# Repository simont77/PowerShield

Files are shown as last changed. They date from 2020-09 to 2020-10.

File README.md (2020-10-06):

# PowerShield
 This design is an extension board for any Raspberry Pi based astronomy tool, like Astroberry or StellarMate.
 The repository contains the electrical (ECAD) and mechanical (MCAD) design files.
 
# Electrical Design (ECAD)
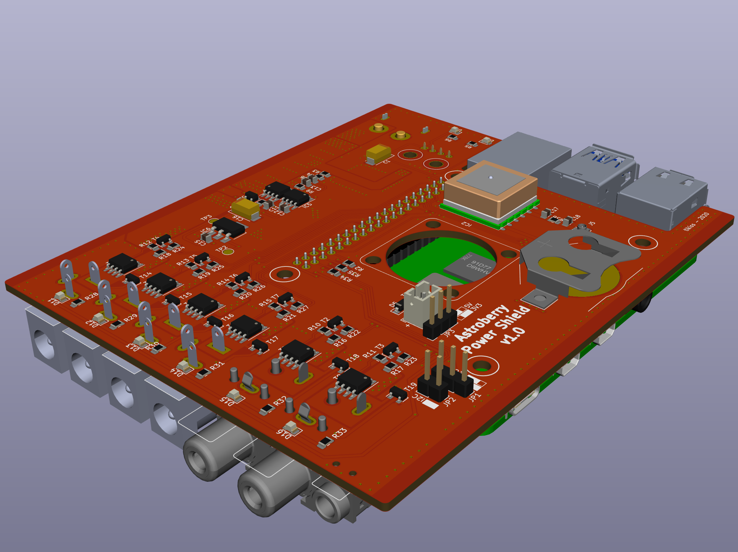
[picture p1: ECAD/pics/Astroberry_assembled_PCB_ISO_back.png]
 
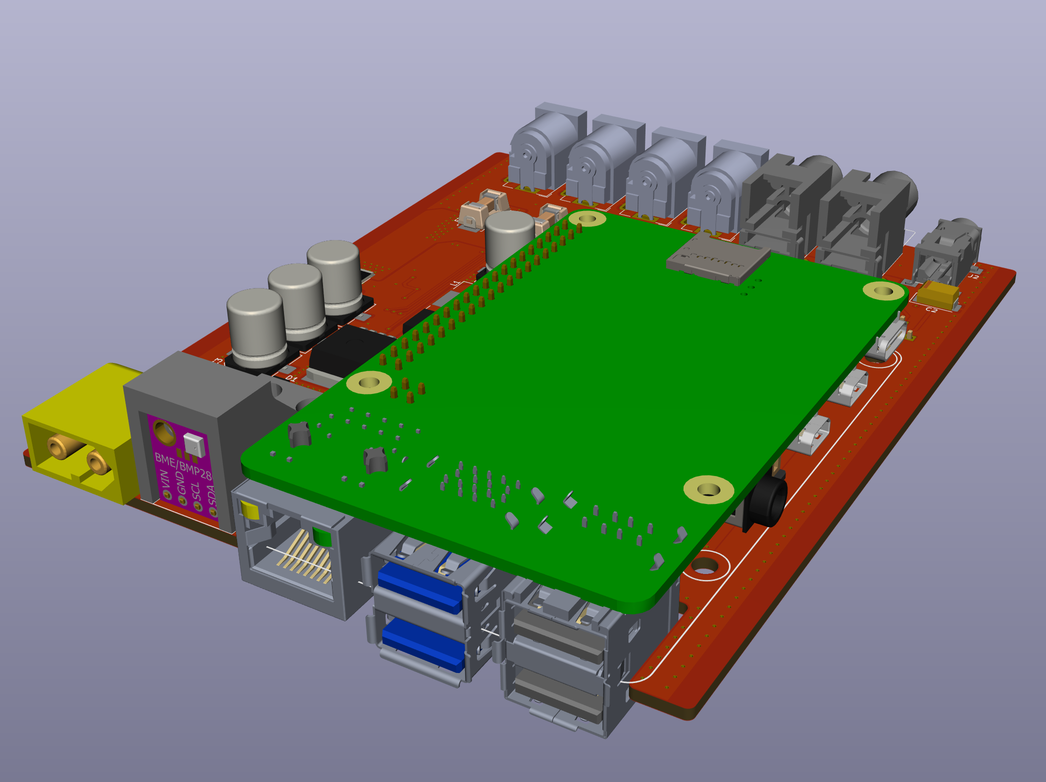
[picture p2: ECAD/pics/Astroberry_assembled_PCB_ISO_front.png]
 
 
## Features
* One power input
* 4pcs switchable (ON/OFF) not regulated outpus, each has maximum 3A load capability (CH1 ... CH4 - DC jack)
* 2pcs switchable (ON/OFF) or PWM controlled outputs, also with maximum 3A load capability for dew heaters (DEW1 and DEW2 - RCA)
* Fuse monitoring signals for each outputs, to detect fuse burn
* Integrated 5V/3A SMPS to power Raspberry Pi
* Integrated BME280 to measure, temperature, pressure and humidity
* Integrated GPS module with integrated antenna
* Connecting external GPS antenna
* Fan connector, supports 3,3V and 5V fans, fan can be switched ON/OFF.
* Input voltage monitoring, maximal range 20V
* Total output current monitoring, maximal range 16A, allowed total ouput curren is 15A
* Reverse polarity protection
* 4 pin 3,5mm jack to connect external sensors, or extension boards, communication interface can be selected with jumpers, I2C or one wire
* LED feedback for each outputs
* LED for GPS, e.g. show 3D fix (usage of this LED is SW dependent)

List of used ports and their funtions will be available in the Wiki section.

## What works
 Every features listed above are tested and working. Testing was done with terminal commands, like "gpio" or with testing scripts.

## What is not working
 Check the "Issues" section.

## What is needed
* INDI driver is on the way: https://github.com/rkaczorek/astroberry-powershield
* I am planning to perform thermal measurement, to see what is board thermal behaviour under maximal load condition.

# Mechanical Design (MCAD)
 Mechanical design was done based on Hammond Extruded Aluminum Enclosures design.
 
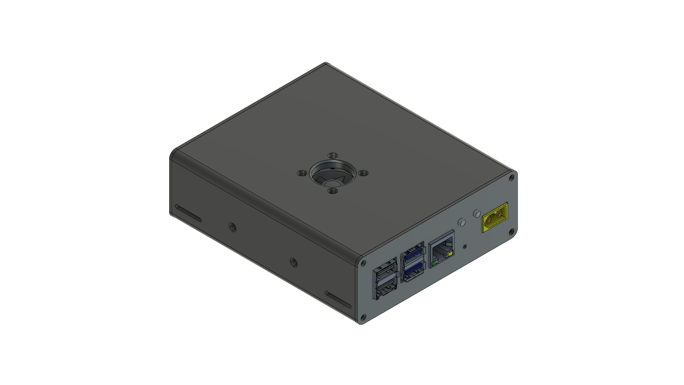
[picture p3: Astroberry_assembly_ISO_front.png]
 
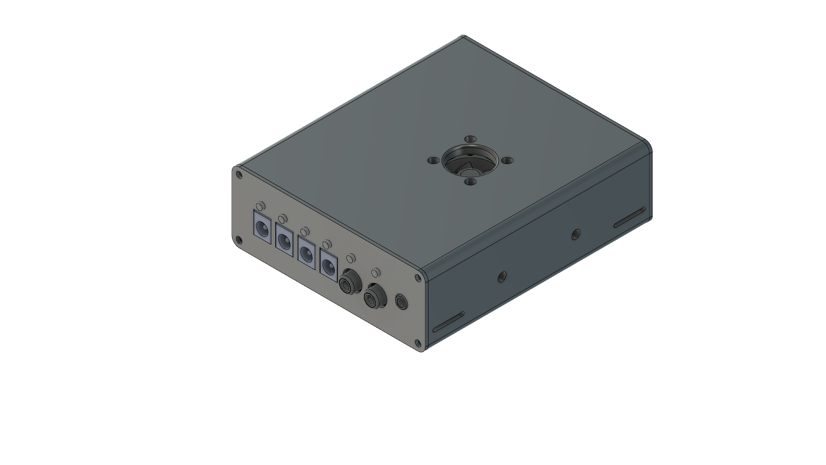
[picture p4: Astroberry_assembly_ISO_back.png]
 
 
 The "extruded" part of the housing is prepared for 3D printing.
 The front and back plates are design in KiCAD as well and manufactured from 1,6mm thick PCB, the panelized gerber files are uploaded in the repository.

# Licence
 The licence is the CERN Open Hardware Licence version 2, and variant CERN-OHL-S
 Check the "LICENCE" file or original location of the licence:
 https://ohwr.org/cern_ohl_s_v2.txt
 
# Donation
If you like the design, think about to support me with a cup of coffee, a glas of beer...
This could help to develop further this design.



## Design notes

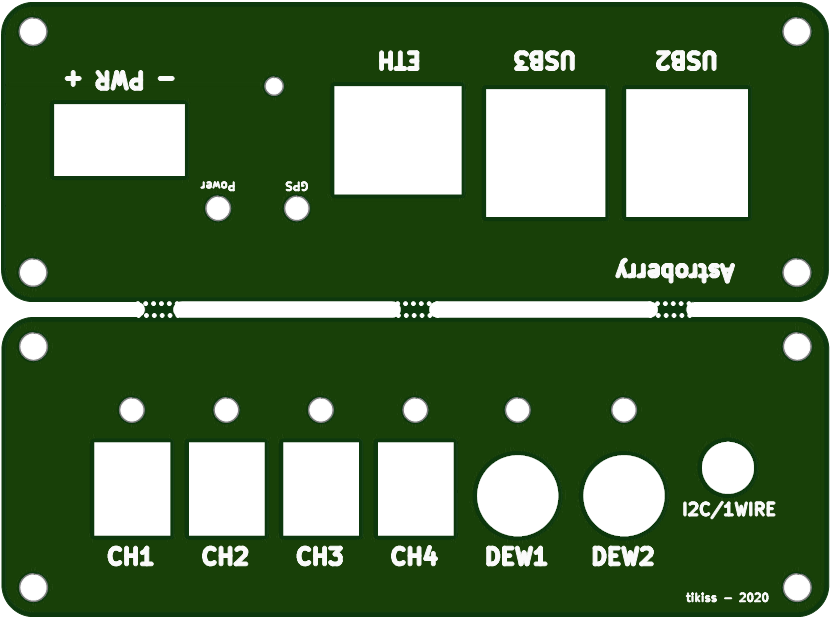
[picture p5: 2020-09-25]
MCAD/Front_Back_Plates/pics/Astroberry_Front_back_Top.png

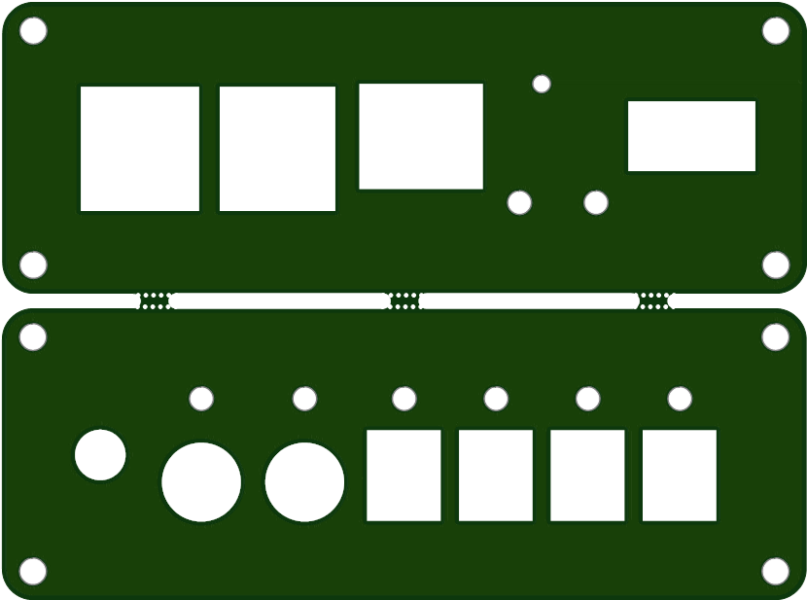
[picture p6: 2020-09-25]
MCAD/Front_Back_Plates/pics/Astroberry_Front_back_Bottom.png

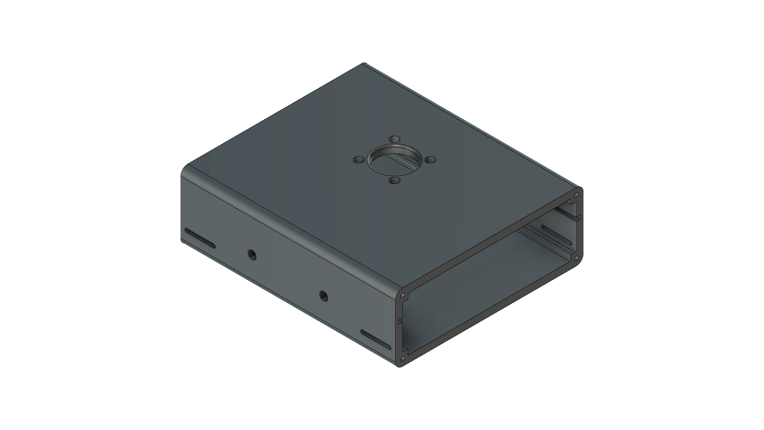
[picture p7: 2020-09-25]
MCAD/Housing/Astroberry_housing_3D.png

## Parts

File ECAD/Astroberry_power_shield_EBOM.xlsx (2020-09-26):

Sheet: EBOM_groupped
Designer | Tibor Kiss
Source: | Astroberry Power Shield v1.0
Date: | 2020 September 26, Saturday 18:41:44
Tool: | Eeschema (5.1.6-0-10_14)
Generator: | bom_csv_grouped_by_value.py
Component Count: | 125
Item | Qty | Reference(s) | Value | LibPart | Footprint | Reichelt
1 | 1 | BT1 | CR2032 | Device:Battery_Cell | Battery:BatteryHolder_Keystone_3002_1x2032 | -
2 | 5 | C1, C2, C7, C8, C16 | 10u | Device:CP | Capacitor_Tantalum_SMD:CP_EIA-6032-28_Kemet-C_Pad2.25x2.35mm_HandSolder | T491C 10U 25
3 | 4 | C3, C4, C5, C14 | 330u | Device:CP | Capacitor_SMD:C_Elec_8x10.2 | VF 330/25 K-F
4 | 7 | C6, C9, C10, C11, C12, C15, C20 | 100n | Device:C | Capacitor_SMD:C_0805_2012Metric | KEM X7R0805 100N
5 | 1 | C13 | 10n | Device:C | Capacitor_SMD:C_0805_2012Metric | KEM X7R0805 10N
6 | 2 | C17, C18 | n.a. | Device:C | Capacitor_SMD:C_0805_2012Metric | -
7 | 1 | C19 | 4,7u | Device:C | Capacitor_SMD:C_0805_2012Metric
8 | 1 | D1 | BZX84C18 | Diode:BZX84Cxx | Diode_SMD:D_SOT-23_ANK | BZX 84-C18 NXP
9 | 1 | D2 | Blue | Device:LED | LED_SMD:LED_0805_2012Metric
10 | 1 | D3 | Green | Device:LED | LED_SMD:LED_0805_2012Metric | SMD-LED 0805 GN
11 | 1 | D4 | SK54C | Diode:B320 | Diode_SMD:D_SMC | SK 54C
12 | 2 | D5, D6 | BAT42W-V | Diode:BAT42W-V | Diode_SMD:D_SOD-123 | BAT 42W
13 | 6 | D11, D12, D13, D14, D15, D16 | Red | Device:LED | LED_SMD:LED_0805_2012Metric | SMD-LED 0805 RT
14 | 2 | D17, D18 | SK 34SMA | Device:D_Schottky | Diode_SMD:D_SMA | SK 34SMA DIO
15 | 6 | F1, F2, F3, F4, F5, F6 | 4A | Device:Fuse | MyFuses:Litt_154_OMNI_BLOK | SMD-HASF 4,0A
16 | 4 | H3, H4, H5, H6 | Fan | Mechanical:MountingHole | MountingHole:MountingHole_3.2mm_M3 | -
17 | 1 | IC1 | INA138 | Amplifier_Current:INA138 | Package_TO_SOT_SMD:SOT-23-5 | INA 138 NA/250
18 | 1 | IC2 | L80-M39 | MyGPS:L80-M39 | MyGPS:L80-M39
19 | 1 | IC3 | LM2596S-5 | Regulator_Switching:LM2596S-5 | Package_TO_SOT_SMD:TO-263-5_TabPin3 | LM 2596 S-5.0
20 | 1 | IC4 | OPA340UA | Amplifier_Operational:OPA340UA | Package_SO:SOIC-8_3.9x4.9mm_P1.27mm | OPA 340 UA
21 | 1 | IC5 | MCP3202 | Analog_ADC:MCP3202 | Package_SO:SOIC-8_3.9x4.9mm_P1.27mm | MCP3202-CI/SN
22 | 1 | IC6 | LM1117-3.3 | Regulator_Linear:LM1117-3.3 | Package_TO_SOT_SMD:SOT-223 | TS 1117 BCW33
23 | 1 | J1 | BME280 | Connector:Conn_01x04_Female | MyMechanic:BME280_holder
24 | 1 | J2 | I2C/1WIRE | MyConnectors:AudioJack_4pin | MyConnectors:LUM_1503_13 | LUM 1503-13V
25 | 1 | J3 | Power | Connector:Conn_01x02_Male | MyConnectors:XT60PW-M20 | -
26 | 1 | J4 | Raspberry Pi | Connector_Generic:Conn_02x20_Odd_Even | MyRaspberry:Raspberry_pi_4_w_mounting_holes | MPE 094-2-040
27 | 1 | J5 | Ext_Ant | Connector:Conn_Coaxial | Connector_Coaxial:U.FL_Molex_MCRF_73412-0110_Vertical
28 | 4 | J6, J7, J8, J9 | DC_Jack_2.1mm | MyConnectors:DC_Jack_2.1mm | MyConnectors:BKL_DC_Jack_2.1mm | DC BU21 90
29 | 1 | J10 | Dew_CH1 | Connector:Conn_Coaxial | MyConnectors:LUM_1553 | LUM 1553 02 SW
30 | 1 | J11 | Dew_CH2 | Connector:Conn_Coaxial | MyConnectors:LUM_1553 | LUM 1553 02 WS
31 | 1 | J12 | FAN | Connector:Conn_01x02_Male | Connector_JST:JST_PH_B2B-PH-K_1x02_P2.00mm_Vertical
32 | 1 | JP1 | 1WIRE/I2C | Jumper:Jumper_3_Bridged12 | Connector_PinHeader_2.54mm:PinHeader_1x03_P2.54mm_Vertical
33 | 1 | JP2 | I2C_CLK | Jumper:Jumper_2_Open | Connector_PinHeader_2.54mm:PinHeader_1x02_P2.54mm_Vertical
34 | 1 | JP3 | 5V/3V3 | Jumper:Jumper_3_Bridged12 | Connector_PinHeader_2.54mm:PinHeader_1x03_P2.54mm_Vertical
35 | 1 | L1 | 33u | Device:L | Inductor_SMD:L_12x12mm_H8mm | L-PIS4728 33¬µ
36 | 8 | R1, R3, R16, R17, R18, R19, R20, R21 | 10k | Device:R | Resistor_SMD:R_0805_2012Metric | RND 0805 1 10K
37 | 9 | R2, R10, R11, R12, R13, R14, R15, R34, R35 | 4k7 | Device:R | Resistor_SMD:R_0805_2012Metric | RND 0805 1 4,7K
38 | 7 | R4, R22, R23, R24, R25, R26, R27 | 1k8 | Device:R | Resistor_SMD:R_0805_2012Metric | RND 0805 1 1,8K
39 | 7 | R5, R28, R29, R30, R31, R32, R33 | 150 | Device:R | Resistor_SMD:R_0805_2012Metric | RND 0805 1 150
40 | 1 | R6 | 270 | Device:R | Resistor_SMD:R_0805_2012Metric | RND 0805 1 270
41 | 1 | R7 | 10m | Device:R | Resistor_SMD:R_2512_6332Metric | ISA SMT-R010-1
42 | 1 | R8 | 100k | Device:R | Resistor_SMD:R_0805_2012Metric | RND 0805 1 100K
43 | 1 | R9 | 15k | Device:R | Resistor_SMD:R_0805_2012Metric | RND 0805 1 15K
44 | 1 | R36 | 0 | Device:R | Resistor_SMD:R_0805_2012Metric
45 | 1 | R37 | 1k | Device:R | Resistor_SMD:R_0805_2012Metric | RND 0805 1 1K
46 | 1 | T1 | AOD403 | Transistor_FET:SUD19P06-60 | Package_TO_SOT_SMD:TO-252-2 | AO D403
47 | 13 | T2, T3, T4, T5, T6, T7, T14, T15, T16, T17, T18, T19, T21 | DTC114E | Transistor_BJT:DTC114E | Package_TO_SOT_SMD:SOT-23 | PDTC 114ET NXP
48 | 6 | T8, T9, T10, T11, T12, T13 | AO4407A | Transistor_FET:IRF7404 | Package_SO:SOIC-8_3.9x4.9mm_P1.27mm | AO 4407A
49 | 1 | T20 | FDN 357N | Transistor_FET:ZXMN3A01F | Package_TO_SOT_SMD:SOT-23 | FDN 357N

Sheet: EBOM
Designer | Tibor Kiss
Source: | Astroberry Power Shield v1.0
Date: | 2020 September 26, Saturday 18:41:44
Tool: | Eeschema (5.1.6-0-10_14)
Generator: | bom_csv_grouped_by_value.py
Component Count: | 125
Reference(s) | Value | LibPart | Footprint | Reichelt
BT1 | CR2032 | Device:Battery_Cell | Battery:BatteryHolder_Keystone_3002_1x2032 | -
C1 | 10u | Device:CP | Capacitor_Tantalum_SMD:CP_EIA-6032-28_Kemet-C_Pad2.25x2.35mm_HandSolder | T491C 10U 25
C2 | 10u | Device:CP | Capacitor_Tantalum_SMD:CP_EIA-6032-28_Kemet-C_Pad2.25x2.35mm_HandSolder | T491C 10U 25
C3 | 330u | Device:CP | Capacitor_SMD:C_Elec_8x10.2 | VF 330/25 K-F
C4 | 330u | Device:CP | Capacitor_SMD:C_Elec_8x10.2 | VF 330/25 K-F
C5 | 330u | Device:CP | Capacitor_SMD:C_Elec_8x10.2 | VF 330/25 K-F
C6 | 100n | Device:C | Capacitor_SMD:C_0805_2012Metric | KEM X7R0805 100N
C7 | 10u | Device:CP | Capacitor_Tantalum_SMD:CP_EIA-6032-28_Kemet-C_Pad2.25x2.35mm_HandSolder | T491C 10U 25
C8 | 10u | Device:CP | Capacitor_Tantalum_SMD:CP_EIA-6032-28_Kemet-C_Pad2.25x2.35mm_HandSolder | T491C 10U 25
C9 | 100n | Device:C | Capacitor_SMD:C_0805_2012Metric | KEM X7R0805 100N
C10 | 100n | Device:C | Capacitor_SMD:C_0805_2012Metric | KEM X7R0805 100N
C11 | 100n | Device:C | Capacitor_SMD:C_0805_2012Metric | KEM X7R0805 100N
C12 | 100n | Device:C | Capacitor_SMD:C_0805_2012Metric | KEM X7R0805 100N
C13 | 10n | Device:C | Capacitor_SMD:C_0805_2012Metric | KEM X7R0805 10N
C14 | 330u | Device:CP | Capacitor_SMD:C_Elec_8x10.2 | VF 330/25 K-F
C15 | 100n | Device:C | Capacitor_SMD:C_0805_2012Metric | KEM X7R0805 100N
C16 | 10u | Device:CP | Capacitor_Tantalum_SMD:CP_EIA-6032-28_Kemet-C_Pad2.25x2.35mm_HandSolder | T491C 10U 25
C17 | n.a. | Device:C | Capacitor_SMD:C_0805_2012Metric | -
C18 | n.a. | Device:C | Capacitor_SMD:C_0805_2012Metric | -
C19 | 4,7u | Device:C | Capacitor_SMD:C_0805_2012Metric
C20 | 100n | Device:C | Capacitor_SMD:C_0805_2012Metric | KEM X7R0805 100N
D1 | BZX84C18 | Diode:BZX84Cxx | Diode_SMD:D_SOT-23_ANK | BZX 84-C18 NXP
D2 | Blue | Device:LED | LED_SMD:LED_0805_2012Metric
D3 | Green | Device:LED | LED_SMD:LED_0805_2012Metric | SMD-LED 0805 GN
D4 | SK54C | Diode:B320 | Diode_SMD:D_SMC | SK 54C
D5 | BAT42W-V | Diode:BAT42W-V | Diode_SMD:D_SOD-123 | BAT 42W
D6 | BAT42W-V | Diode:BAT42W-V | Diode_SMD:D_SOD-123 | BAT 42W
D11 | Red | Device:LED | LED_SMD:LED_0805_2012Metric | SMD-LED 0805 RT
D12 | Red | Device:LED | LED_SMD:LED_0805_2012Metric | SMD-LED 0805 RT
D13 | Red | Device:LED | LED_SMD:LED_0805_2012Metric | SMD-LED 0805 RT
D14 | Red | Device:LED | LED_SMD:LED_0805_2012Metric | SMD-LED 0805 RT
D15 | Red | Device:LED | LED_SMD:LED_0805_2012Metric | SMD-LED 0805 RT
D16 | Red | Device:LED | LED_SMD:LED_0805_2012Metric | SMD-LED 0805 RT
D17 | SK 34SMA | Device:D_Schottky | Diode_SMD:D_SMA | SK 34SMA DIO
D18 | SK 34SMA | Device:D_Schottky | Diode_SMD:D_SMA | SK 34SMA DIO
F1 | 4A | Device:Fuse | MyFuses:Litt_154_OMNI_BLOK | SMD-HASF 4,0A
F2 | 4A | Device:Fuse | MyFuses:Litt_154_OMNI_BLOK | SMD-HASF 4,0A
F3 | 4A | Device:Fuse | MyFuses:Litt_154_OMNI_BLOK | SMD-HASF 4,0A
F4 | 4A | Device:Fuse | MyFuses:Litt_154_OMNI_BLOK | SMD-HASF 4,0A
F5 | 4A | Device:Fuse | MyFuses:Litt_154_OMNI_BLOK | SMD-HASF 4,0A
F6 | 4A | Device:Fuse | MyFuses:Litt_154_OMNI_BLOK | SMD-HASF 4,0A
H3 | Fan | Mechanical:MountingHole | MountingHole:MountingHole_3.2mm_M3 | -
H4 | Fan | Mechanical:MountingHole | MountingHole:MountingHole_3.2mm_M3 | -
H5 | Fan | Mechanical:MountingHole | MountingHole:MountingHole_3.2mm_M3 | -
H6 | Fan | Mechanical:MountingHole | MountingHole:MountingHole_3.2mm_M3 | -
IC1 | INA138 | Amplifier_Current:INA138 | Package_TO_SOT_SMD:SOT-23-5 | INA 138 NA/250
IC2 | L80-M39 | MyGPS:L80-M39 | MyGPS:L80-M39
IC3 | LM2596S-5 | Regulator_Switching:LM2596S-5 | Package_TO_SOT_SMD:TO-263-5_TabPin3 | LM 2596 S-5.0
IC4 | OPA340UA | Amplifier_Operational:OPA340UA | Package_SO:SOIC-8_3.9x4.9mm_P1.27mm | OPA 340 UA
IC5 | MCP3202 | Analog_ADC:MCP3202 | Package_SO:SOIC-8_3.9x4.9mm_P1.27mm | MCP3202-CI/SN
IC6 | LM1117-3.3 | Regulator_Linear:LM1117-3.3 | Package_TO_SOT_SMD:SOT-223 | TS 1117 BCW33
J1 | BME280 | Connector:Conn_01x04_Female | MyMechanic:BME280_holder
J2 | I2C/1WIRE | MyConnectors:AudioJack_4pin | MyConnectors:LUM_1503_13 | LUM 1503-13V
J3 | Power | Connector:Conn_01x02_Male | MyConnectors:XT60PW-M20 | -
J4 | Raspberry Pi | Connector_Generic:Conn_02x20_Odd_Even | MyRaspberry:Raspberry_pi_4_w_mounting_holes | MPE 094-2-040
J5 | Ext_Ant | Connector:Conn_Coaxial | Connector_Coaxial:U.FL_Molex_MCRF_73412-0110_Vertical
J6 | DC_Jack_2.1mm | MyConnectors:DC_Jack_2.1mm | MyConnectors:BKL_DC_Jack_2.1mm | DC BU21 90
J7 | DC_Jack_2.1mm | MyConnectors:DC_Jack_2.1mm | MyConnectors:BKL_DC_Jack_2.1mm | DC BU21 90
J8 | DC_Jack_2.1mm | MyConnectors:DC_Jack_2.1mm | MyConnectors:BKL_DC_Jack_2.1mm | DC BU21 90
J9 | DC_Jack_2.1mm | MyConnectors:DC_Jack_2.1mm | MyConnectors:BKL_DC_Jack_2.1mm | DC BU21 90
J10 | Dew_CH1 | Connector:Conn_Coaxial | MyConnectors:LUM_1553 | LUM 1553 02 SW
J11 | Dew_CH2 | Connector:Conn_Coaxial | MyConnectors:LUM_1553 | LUM 1553 02 WS
J12 | FAN | Connector:Conn_01x02_Male | Connector_JST:JST_PH_B2B-PH-K_1x02_P2.00mm_Vertical
JP1 | 1WIRE/I2C | Jumper:Jumper_3_Bridged12 | Connector_PinHeader_2.54mm:PinHeader_1x03_P2.54mm_Vertical
JP2 | I2C_CLK | Jumper:Jumper_2_Open | Connector_PinHeader_2.54mm:PinHeader_1x02_P2.54mm_Vertical
JP3 | 5V/3V3 | Jumper:Jumper_3_Bridged12 | Connector_PinHeader_2.54mm:PinHeader_1x03_P2.54mm_Vertical
L1 | 33u | Device:L | Inductor_SMD:L_12x12mm_H8mm | L-PIS4728 33¬µ
R1 | 10k | Device:R | Resistor_SMD:R_0805_2012Metric | RND 0805 1 10K
R2 | 4k7 | Device:R | Resistor_SMD:R_0805_2012Metric | RND 0805 1 4,7K
R3 | 10k | Device:R | Resistor_SMD:R_0805_2012Metric | RND 0805 1 10K
R4 | 1k8 | Device:R | Resistor_SMD:R_0805_2012Metric | RND 0805 1 1,8K
R5 | 150 | Device:R | Resistor_SMD:R_0805_2012Metric | RND 0805 1 150
R6 | 270 | Device:R | Resistor_SMD:R_0805_2012Metric | RND 0805 1 270
R7 | 10m | Device:R | Resistor_SMD:R_2512_6332Metric | ISA SMT-R010-1
R8 | 100k | Device:R | Resistor_SMD:R_0805_2012Metric | RND 0805 1 100K
R9 | 15k | Device:R | Resistor_SMD:R_0805_2012Metric | RND 0805 1 15K
R10 | 4k7 | Device:R | Resistor_SMD:R_0805_2012Metric | RND 0805 1 4,7K
R11 | 4k7 | Device:R | Resistor_SMD:R_0805_2012Metric | RND 0805 1 4,7K
R12 | 4k7 | Device:R | Resistor_SMD:R_0805_2012Metric | RND 0805 1 4,7K
R13 | 4k7 | Device:R | Resistor_SMD:R_0805_2012Metric | RND 0805 1 4,7K
R14 | 4k7 | Device:R | Resistor_SMD:R_0805_2012Metric | RND 0805 1 4,7K
R15 | 4k7 | Device:R | Resistor_SMD:R_0805_2012Metric | RND 0805 1 4,7K
R16 | 10k | Device:R | Resistor_SMD:R_0805_2012Metric | RND 0805 1 10K
R17 | 10k | Device:R | Resistor_SMD:R_0805_2012Metric | RND 0805 1 10K
R18 | 10k | Device:R | Resistor_SMD:R_0805_2012Metric | RND 0805 1 10K
R19 | 10k | Device:R | Resistor_SMD:R_0805_2012Metric | RND 0805 1 10K
R20 | 10k | Device:R | Resistor_SMD:R_0805_2012Metric | RND 0805 1 10K
R21 | 10k | Device:R | Resistor_SMD:R_0805_2012Metric | RND 0805 1 10K
R22 | 1k8 | Device:R | Resistor_SMD:R_0805_2012Metric | RND 0805 1 1,8K
R23 | 1k8 | Device:R | Resistor_SMD:R_0805_2012Metric | RND 0805 1 1,8K
R24 | 1k8 | Device:R | Resistor_SMD:R_0805_2012Metric | RND 0805 1 1,8K
R25 | 1k8 | Device:R | Resistor_SMD:R_0805_2012Metric | RND 0805 1 1,8K
R26 | 1k8 | Device:R | Resistor_SMD:R_0805_2012Metric | RND 0805 1 1,8K
R27 | 1k8 | Device:R | Resistor_SMD:R_0805_2012Metric | RND 0805 1 1,8K
R28 | 150 | Device:R | Resistor_SMD:R_0805_2012Metric | RND 0805 1 150
R29 | 150 | Device:R | Resistor_SMD:R_0805_2012Metric | RND 0805 1 150
R30 | 150 | Device:R | Resistor_SMD:R_0805_2012Metric | RND 0805 1 150
R31 | 150 | Device:R | Resistor_SMD:R_0805_2012Metric | RND 0805 1 150
R32 | 150 | Device:R | Resistor_SMD:R_0805_2012Metric | RND 0805 1 150
R33 | 150 | Device:R | Resistor_SMD:R_0805_2012Metric | RND 0805 1 150
R34 | 4k7 | Device:R | Resistor_SMD:R_0805_2012Metric | RND 0805 1 4,7K
R35 | 4k7 | Device:R | Resistor_SMD:R_0805_2012Metric | RND 0805 1 4,7K
R36 | 0 | Device:R | Resistor_SMD:R_0805_2012Metric
R37 | 1k | Device:R | Resistor_SMD:R_0805_2012Metric | RND 0805 1 1K
T1 | AOD403 | Transistor_FET:SUD19P06-60 | Package_TO_SOT_SMD:TO-252-2 | AO D403
T2 | DTC114E | Transistor_BJT:DTC114E | Package_TO_SOT_SMD:SOT-23 | PDTC 114ET NXP
T3 | DTC114E | Transistor_BJT:DTC114E | Package_TO_SOT_SMD:SOT-23 | PDTC 114ET NXP
T4 | DTC114E | Transistor_BJT:DTC114E | Package_TO_SOT_SMD:SOT-23 | PDTC 114ET NXP
T5 | DTC114E | Transistor_BJT:DTC114E | Package_TO_SOT_SMD:SOT-23 | PDTC 114ET NXP
T6 | DTC114E | Transistor_BJT:DTC114E | Package_TO_SOT_SMD:SOT-23 | PDTC 114ET NXP
T7 | DTC114E | Transistor_BJT:DTC114E | Package_TO_SOT_SMD:SOT-23 | PDTC 114ET NXP
T8 | AO4407A | Transistor_FET:IRF7404 | Package_SO:SOIC-8_3.9x4.9mm_P1.27mm | AO 4407A
T9 | AO4407A | Transistor_FET:IRF7404 | Package_SO:SOIC-8_3.9x4.9mm_P1.27mm | AO 4407A
T10 | AO4407A | Transistor_FET:IRF7404 | Package_SO:SOIC-8_3.9x4.9mm_P1.27mm | AO 4407A
T11 | AO4407A | Transistor_FET:IRF7404 | Package_SO:SOIC-8_3.9x4.9mm_P1.27mm | AO 4407A
T12 | AO4407A | Transistor_FET:IRF7404 | Package_SO:SOIC-8_3.9x4.9mm_P1.27mm | AO 4407A
T13 | AO4407A | Transistor_FET:IRF7404 | Package_SO:SOIC-8_3.9x4.9mm_P1.27mm | AO 4407A
T14 | DTC114E | Transistor_BJT:DTC114E | Package_TO_SOT_SMD:SOT-23 | PDTC 114ET NXP
T15 | DTC114E | Transistor_BJT:DTC114E | Package_TO_SOT_SMD:SOT-23 | PDTC 114ET NXP
T16 | DTC114E | Transistor_BJT:DTC114E | Package_TO_SOT_SMD:SOT-23 | PDTC 114ET NXP
T17 | DTC114E | Transistor_BJT:DTC114E | Package_TO_SOT_SMD:SOT-23 | PDTC 114ET NXP
T18 | DTC114E | Transistor_BJT:DTC114E | Package_TO_SOT_SMD:SOT-23 | PDTC 114ET NXP
T19 | DTC114E | Transistor_BJT:DTC114E | Package_TO_SOT_SMD:SOT-23 | PDTC 114ET NXP
T20 | FDN 357N | Transistor_FET:ZXMN3A01F | Package_TO_SOT_SMD:SOT-23 | FDN 357N
T21 | DTC114E | Transistor_BJT:DTC114E | Package_TO_SOT_SMD:SOT-23 | PDTC 114ET NXP

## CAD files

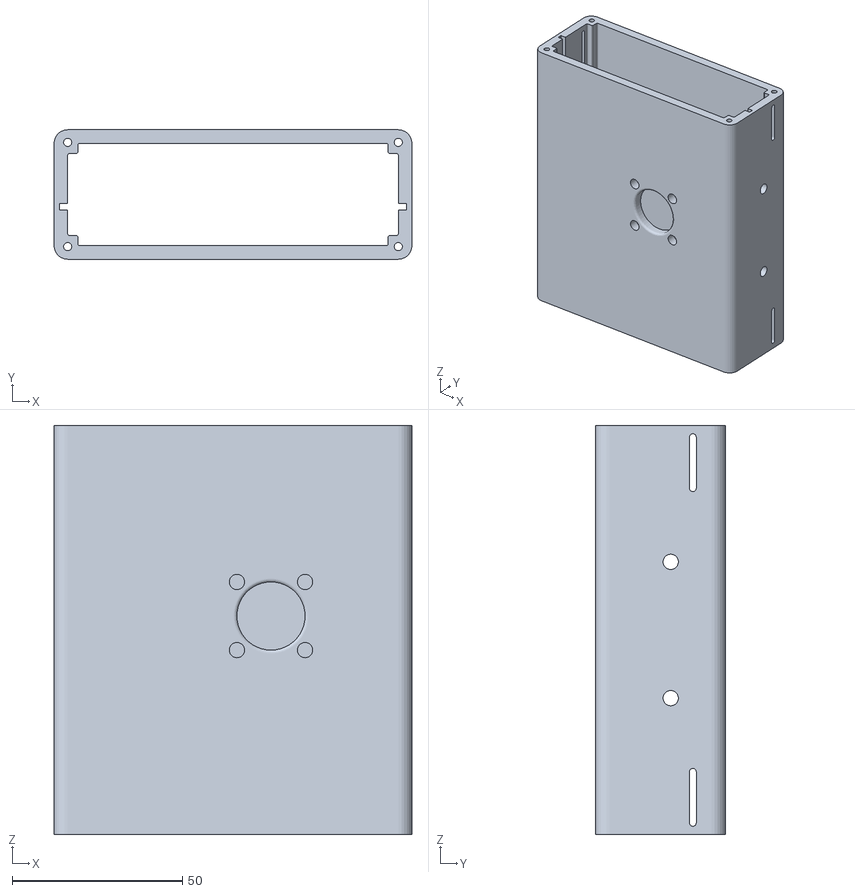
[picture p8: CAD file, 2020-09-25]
MCAD/Housing/Astroberry_housing.stl
105.0 x 38.0 x 120.0

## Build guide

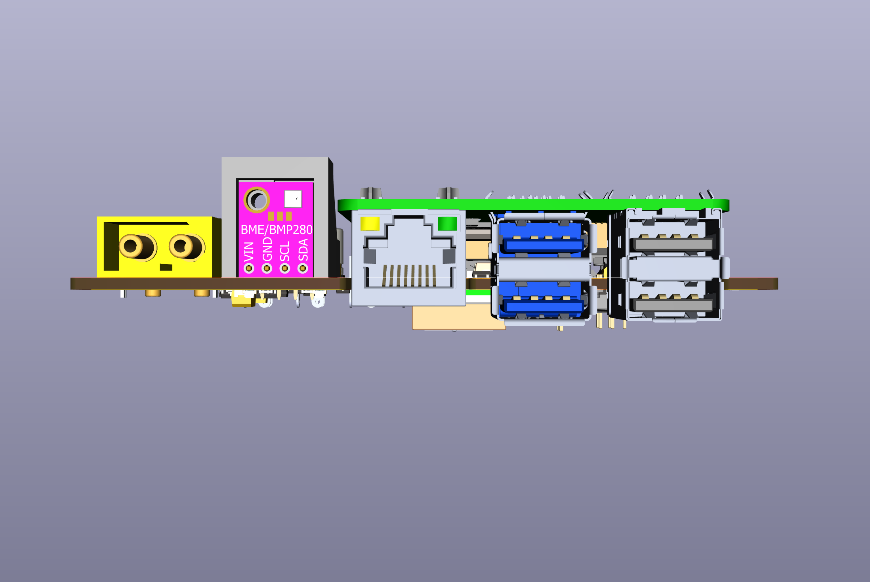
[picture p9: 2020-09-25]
ECAD/pics/Astroberry_assembled_PCB_front.png

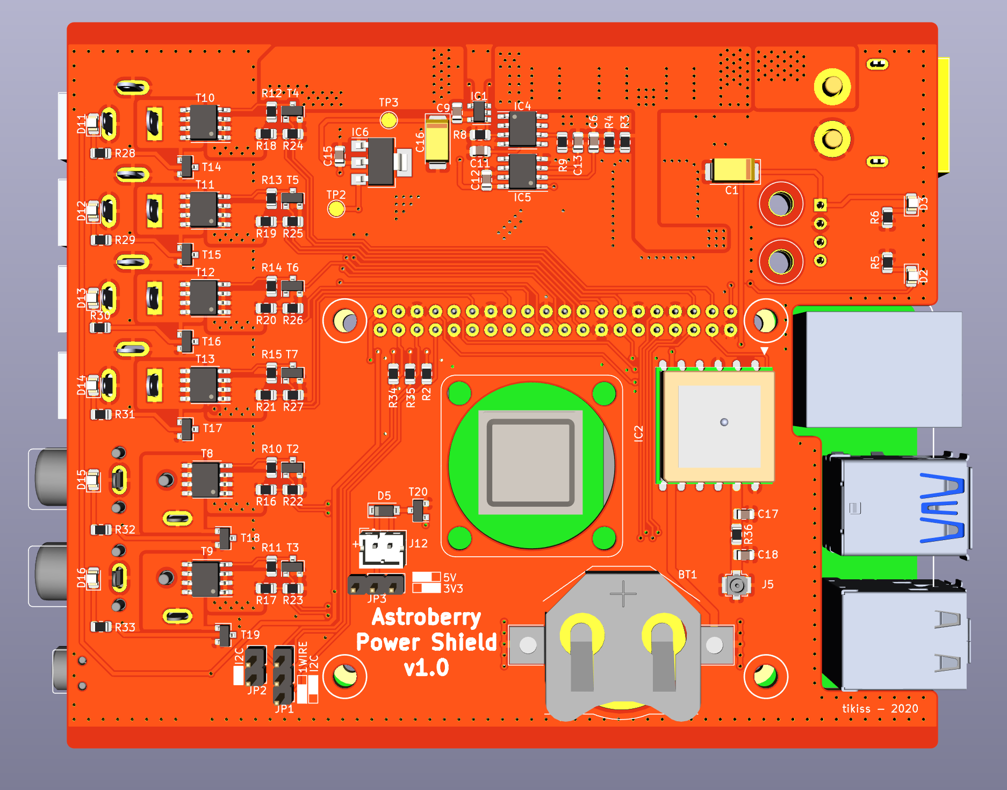
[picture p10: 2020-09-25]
ECAD/pics/Astroberry_assembled_PCB_top.png

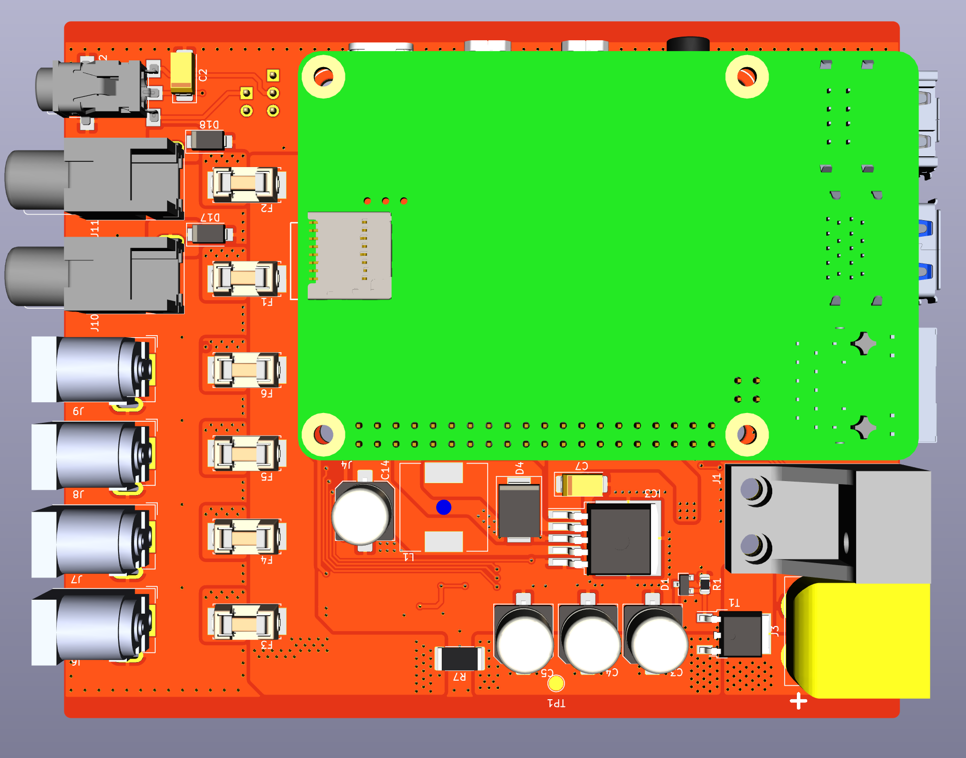
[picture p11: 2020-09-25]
ECAD/pics/Astroberry_assembled_PCB_bottom.png

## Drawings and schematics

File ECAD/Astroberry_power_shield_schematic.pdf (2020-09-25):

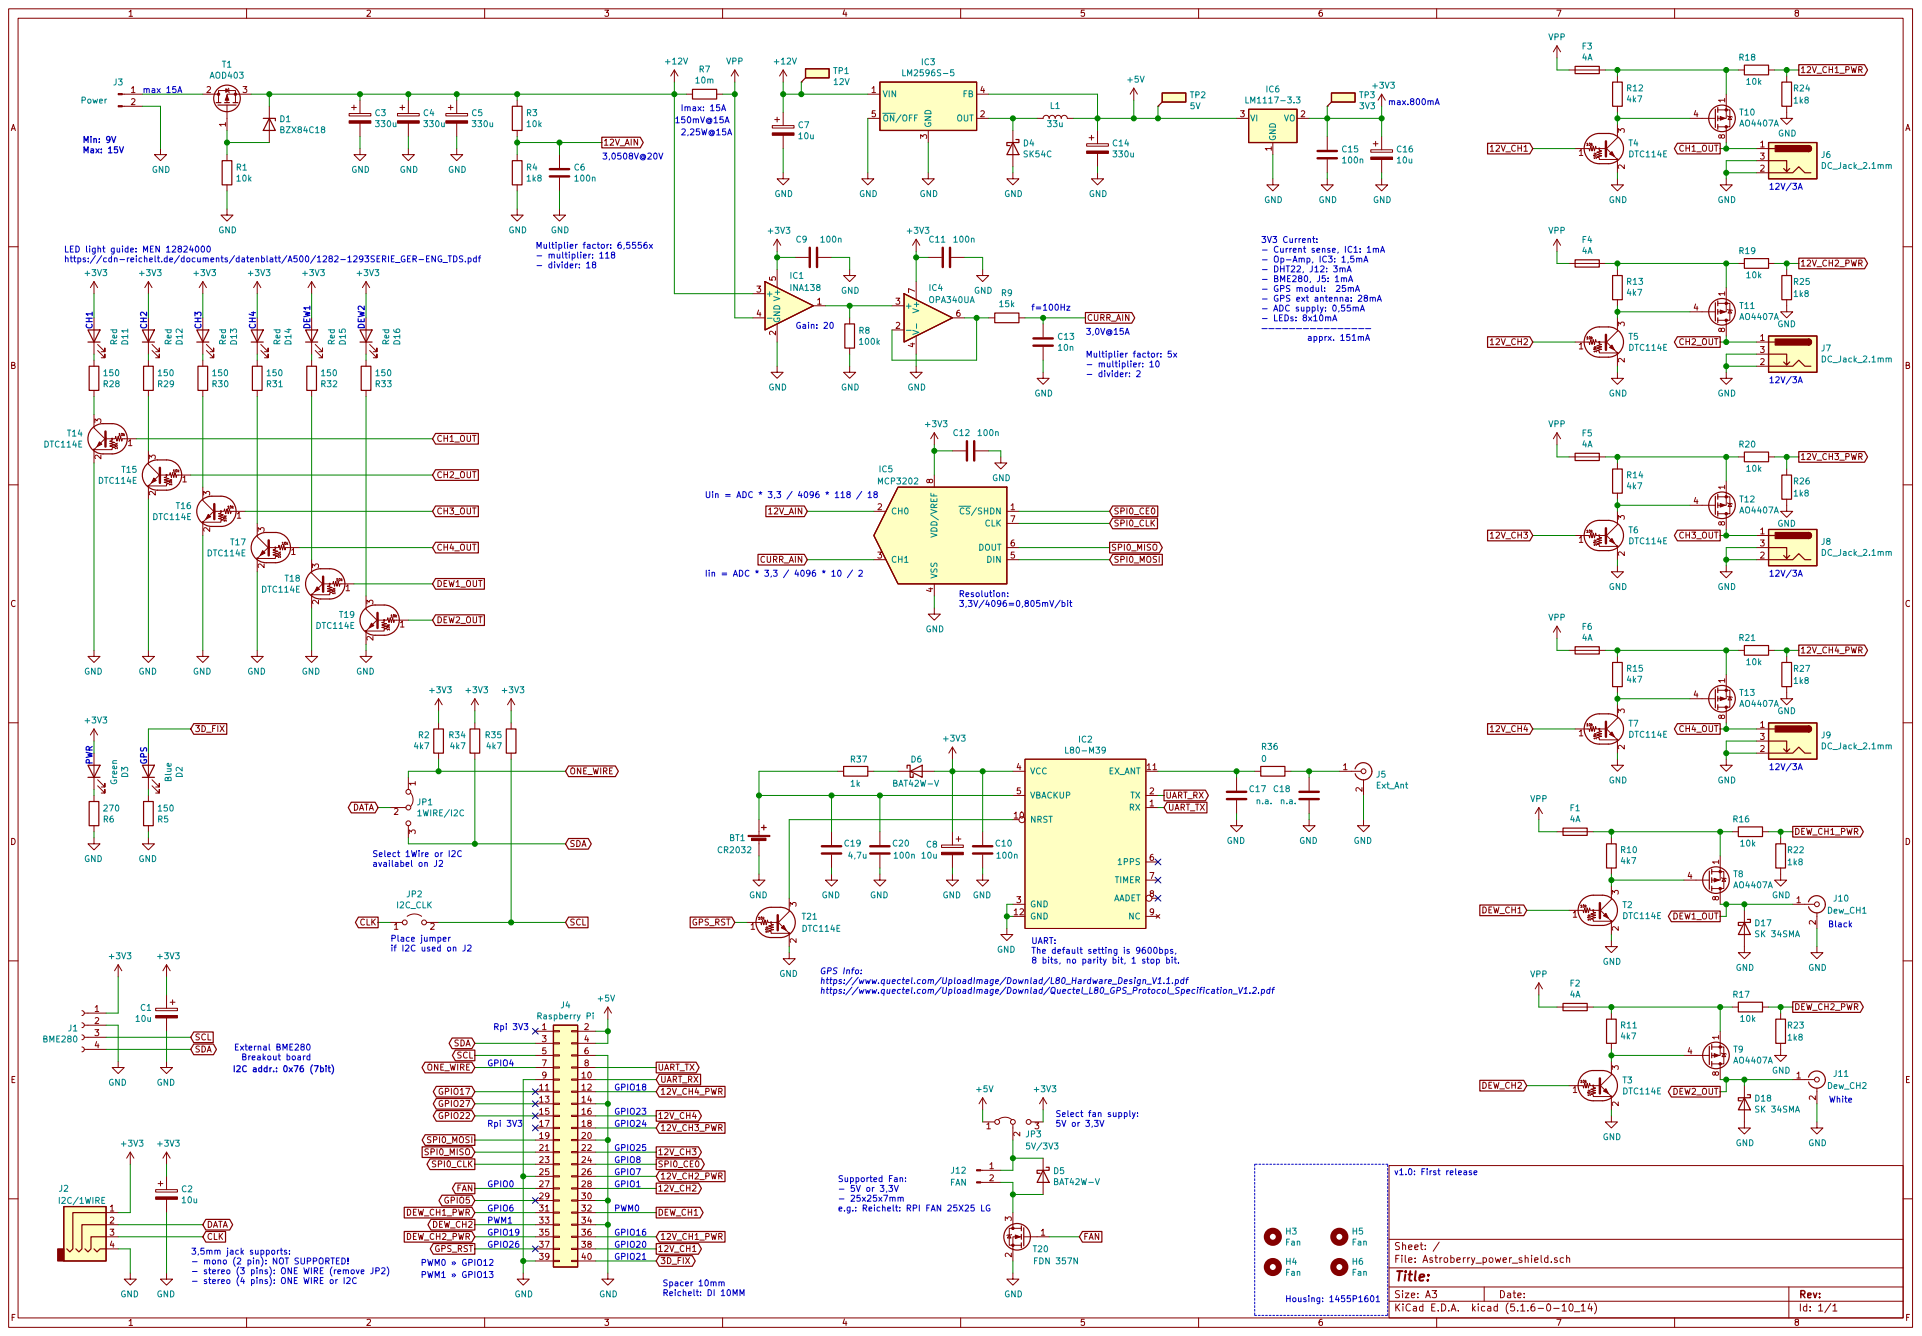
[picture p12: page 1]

LED light guide: MEN 12824000

4 DIN 5 DOUT 6 CLK 7 VDD/VREF

12V/3A GPS Info: https://www.quectel.com/UploadImage/Downlad/L80_Hardware_Design_V1.1.pdf

2 3 T21 DTC114E RX 1 NRST 10 EX_ANT 11 GND 12 TX 2 GND 3 VCC 4 VBACKUP 5

Select 1Wire or I2C
availabel on J2 Place jumper

https://www.quectel.com/UploadImage/Downlad/Quectel_L80_GPS_Protocol_Specification_V1.2.pdf UART: The default setting is 9600bps,

e.g.: Reichelt: RPI FAN 25X25 LG

3,5mm jack supports:
- mono (2 pin): NOT SUPPORTED!
- stereo (3 pins): ONE WIRE (remove JP2)

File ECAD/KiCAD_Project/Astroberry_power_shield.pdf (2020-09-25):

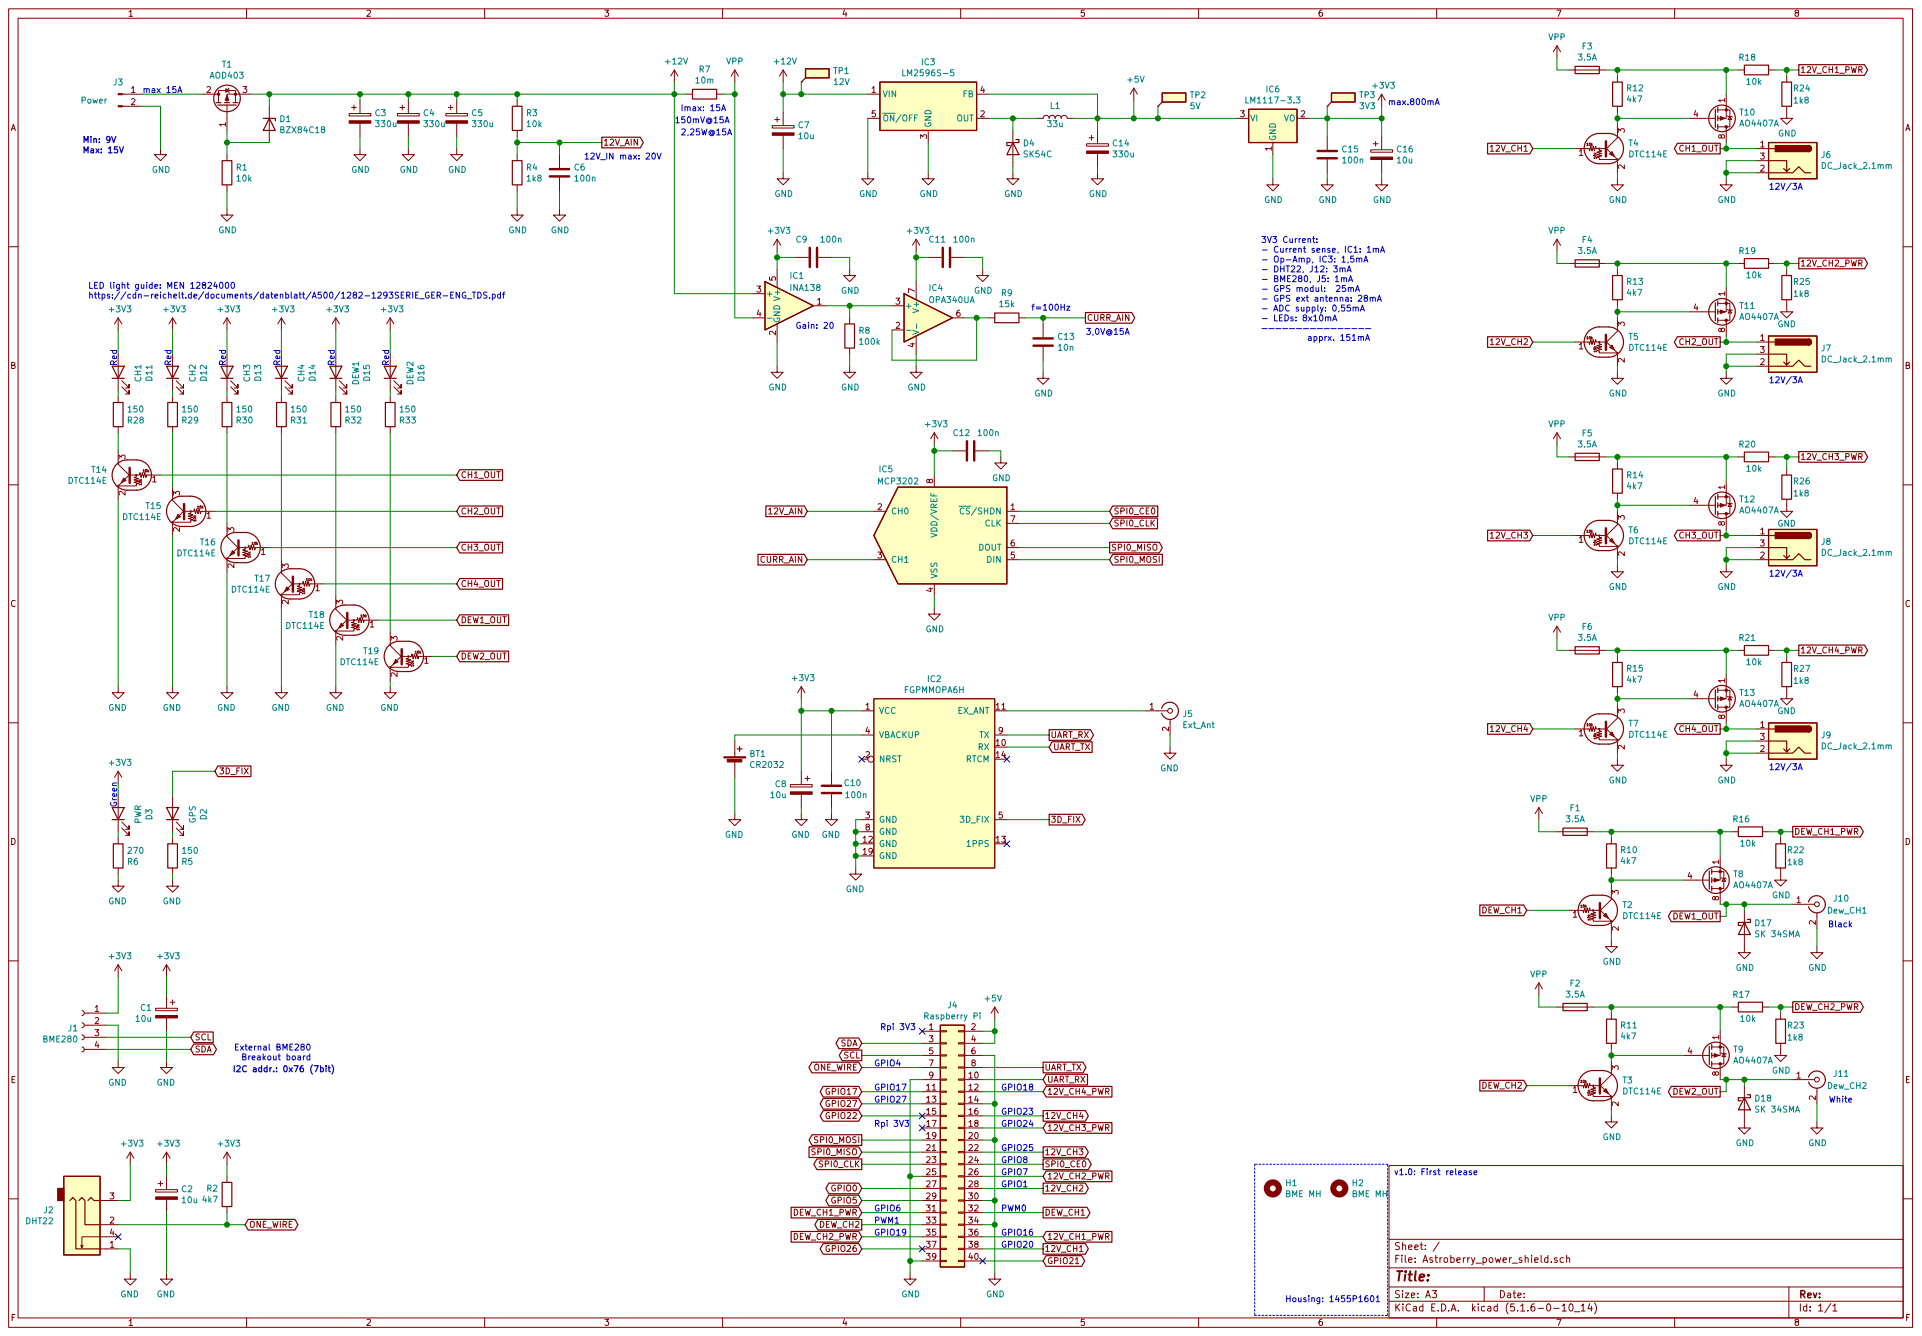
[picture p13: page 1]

LED light guide: MEN 12824000
https://cdn-reichelt.de/documents/datenblatt/A500/1282-1293SERIE_GER-ENG_TDS.pdf Red Green

4 DIN 5 DOUT 6 CLK 7 VDD/VREF

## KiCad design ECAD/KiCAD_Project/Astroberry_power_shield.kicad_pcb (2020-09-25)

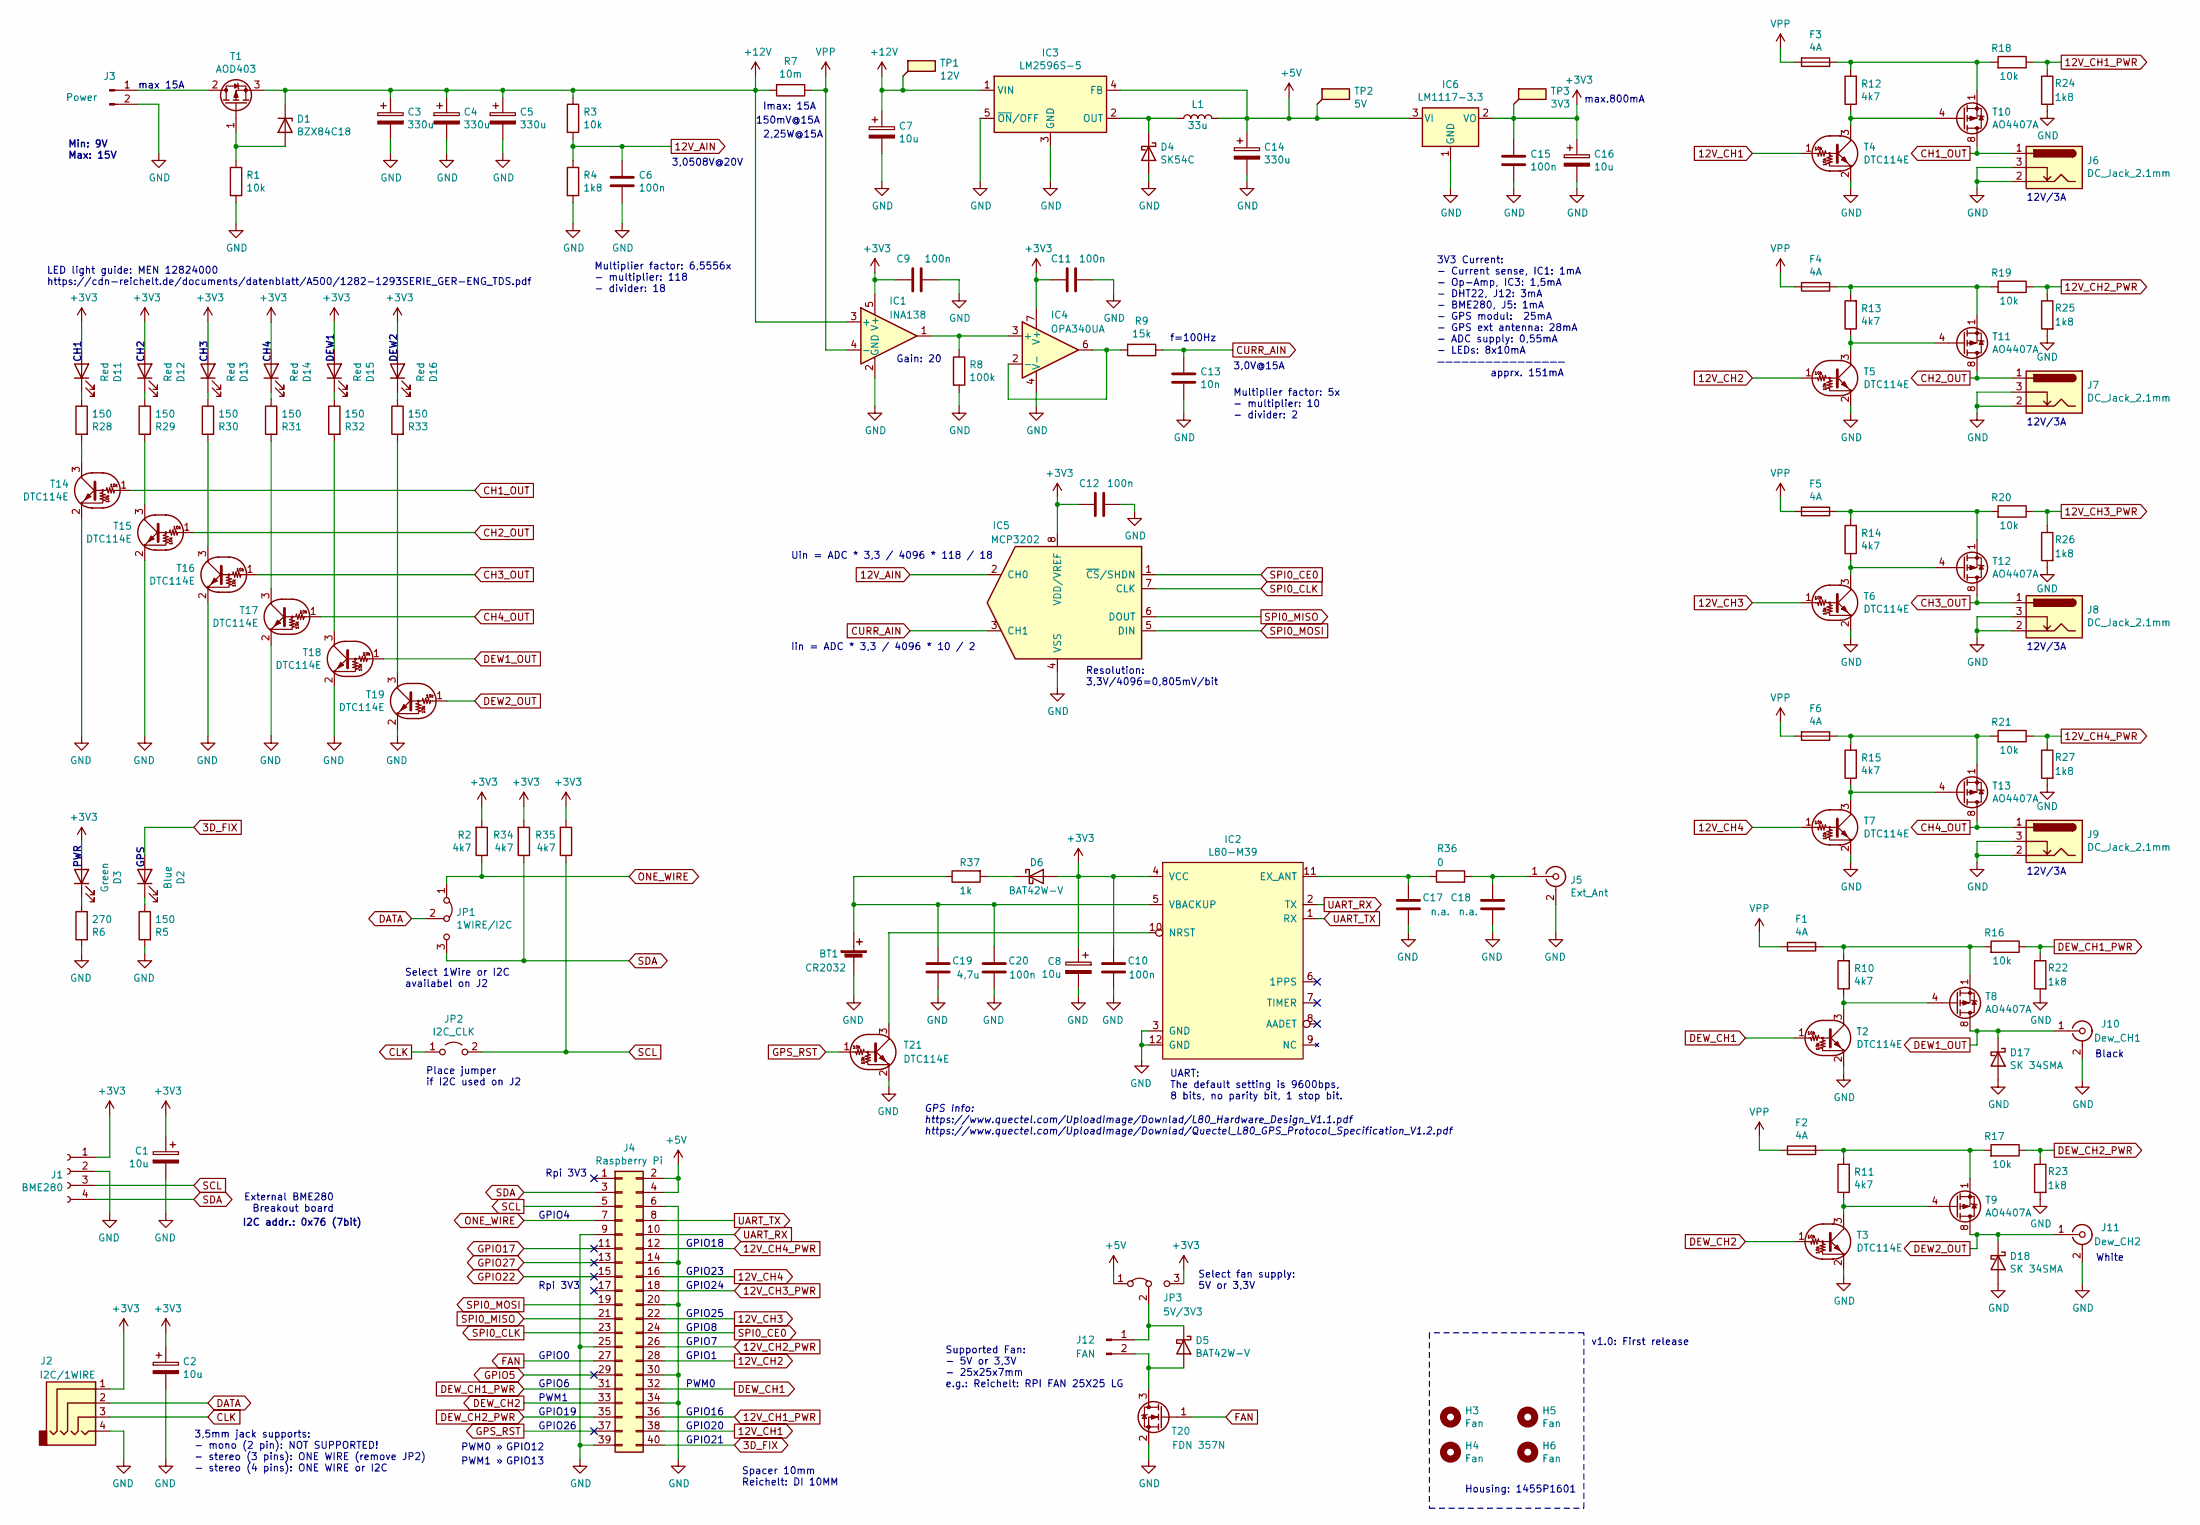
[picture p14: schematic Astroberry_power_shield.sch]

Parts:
BT1: CR2032; BatteryHolder_Keystone_3002_1x2032
C1, C2, C7, C8, C16: 10u; CP_EIA-6032-28_Kemet-C_Pad2.25x2.35mm_HandSolder
C3, C4, C5, C14: 330u; C_Elec_8x10.2; JLCPCB C286135
C6, C9, C10, C11, C12, C15, C20: 100n; C_0805_2012Metric; JLCPCB C49678
C13: 10n; C_0805_2012Metric; JLCPCB C1710
C17, C18: n.a.; C_0805_2012Metric
C19: 4,7u; C_0805_2012Metric; JLCPCB C1779
D1: BZX84C18; D_SOT-23_ANK; JLCPCB C35678
D2: Blue; LED_0805_2012Metric; JLCPCB C2293
D3: Green; LED_0805_2012Metric; JLCPCB C84257
D4: SK54C; D_SMC; JLCPCB C57579
D5, D6: BAT42W-V; D_SOD-123; JLCPCB C144923
D11, D12, D13, D14, D15, D16: Red; LED_0805_2012Metric; JLCPCB C84256
D17, D18: SK 34SMA; D_SMA; JLCPCB C65008
F1, F2, F3, F4, F5, F6: 4A; Litt_154_OMNI_BLOK
H3, H4, H5, H6: Fan; MountingHole_3.2mm_M3
IC1: INA138; SOT-23-5; JLCPCB C47914
IC2: L80-M39
IC3: LM2596S-5; TO-263-5_TabPin3; JLCPCB C10002
IC4: OPA340UA; SOIC-8_3.9x4.9mm_P1.27mm; JLCPCB C12247
IC5: MCP3202; SOIC-8_3.9x4.9mm_P1.27mm
IC6: LM1117-3.3; SOT-223; JLCPCB C126027
J1: BME280; BME280_holder
J2: I2C/1WIRE; LUM_1503_13
J3: Power; XT60PW-M20
J4: Raspberry Pi; Raspberry_pi_4_w_mounting_holes
J5: Ext_Ant; U.FL_Molex_MCRF_73412-0110_Vertical
J6, J7, J8, J9: DC_Jack_2.1mm; BKL_DC_Jack_2.1mm
J10: Dew_CH1; LUM_1553
J11: Dew_CH2; LUM_1553
J12: FAN; JST_PH_B2B-PH-K_1x02_P2.00mm_Vertical
JP1: 1WIRE/I2C; PinHeader_1x03_P2.54mm_Vertical
JP2: I2C_CLK; PinHeader_1x02_P2.54mm_Vertical
JP3: 5V/3V3; PinHeader_1x03_P2.54mm_Vertical
L1: 33u; L_12x12mm_H8mm; JLCPCB C169375
R1, R3, R16, R17, R18, R19, R20, R21: 10k; R_0805_2012Metric; JLCPCB C17414
R2, R10, R11, R12, R13, R14, R15, R34, R35: 4k7; R_0805_2012Metric; JLCPCB C17673
R4, R22, R23, R24, R25, R26, R27: 1k8; R_0805_2012Metric; JLCPCB C17398
R5, R28, R29, R30, R31, R32, R33: 150; R_0805_2012Metric; JLCPCB C17471
R6: 270; R_0805_2012Metric; JLCPCB C17590
R7: 10m; R_2512_6332Metric; JLCPCB C76242
R8: 100k; R_0805_2012Metric; JLCPCB C17407
R9: 15k; R_0805_2012Metric; JLCPCB C17475
R36: 0; R_0805_2012Metric; JLCPCB C17477
R37: 1k; R_0805_2012Metric; JLCPCB C17513
T1: AOD403; TO-252-2; JLCPCB C28969
T2, T3, T4, T5, T6, T7, T14, T15, T16, T17, T18, T19, T21: DTC114E; SOT-23; JLCPCB C14303
T8, T9, T10, T11, T12, T13: AO4407A; SOIC-8_3.9x4.9mm_P1.27mm; JLCPCB C16072
T20: FDN 357N; SOT-23
TP1: 12V; TestPoint_Pad_D2.0mm
TP2: 5V; TestPoint_Pad_D2.0mm
TP3: 3V3; TestPoint_Pad_D2.0mm

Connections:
3D_FIX: D2.2 (A), J4.40
12V_AIN: C6.1, IC5.2 (CH0), R3.2, R4.1
12V_CH1: J4.38, T4.1 (B)
12V_CH1_PWR: J4.36, R18.1, R24.1
12V_CH2: J4.28, T5.1 (B)
12V_CH2_PWR: J4.26, R19.1, R25.1
12V_CH3: J4.22, T6.1 (B)
12V_CH3_PWR: J4.18, R20.1, R26.1
12V_CH4: J4.16, T7.1 (B)
12V_CH4_PWR: J4.12, R21.1, R27.1
+3V3: C1.1, C2.1, C8.1, C9.2, C10.2, C11.2, C12.2, C15.1, C16.1, D3.2 (A), D6.2 (A), D11.2 (A), D12.2 (A), D13.2 (A), D14.2 (A), D15.2 (A), D16.2 (A), IC1.5 (V+), IC2.4 (VCC), IC4.7 (V+), IC5.8 (VDD/VREF), IC6.2 (VO), J1.1, J2.1, JP3.3 (B), R2.2, R34.2, R35.2, TP3.1
+5V: C14.1, IC3.4 (FB), IC6.3 (VI), J4.2, J4.4, JP3.1 (A), L1.2, TP2.1
+12V: C3.1, C4.1, C5.1, C7.1, D1.1 (K), IC1.3 (+), IC3.1 (VIN), R3.1, R7.2, T1.3 (S), TP1.1
CH1_OUT: J6.1, T10.5 (D), T10.6 (D), T10.7 (D), T10.8 (D), T14.1 (B)
CH2_OUT: J7.1, T11.5 (D), T11.6 (D), T11.7 (D), T11.8 (D), T15.1 (B)
CH3_OUT: J8.1, T12.5 (D), T12.6 (D), T12.7 (D), T12.8 (D), T16.1 (B)
CH4_OUT: J9.1, T13.5 (D), T13.6 (D), T13.7 (D), T13.8 (D), T17.1 (B)
CLK: J2.3, JP2.1 (A)
CURR_AIN: C13.1, IC5.3 (CH1), R9.1
DATA: J2.2, JP1.2 (C)
DEW1_OUT: D17.1 (K), J10.1 (In), T8.5 (D), T8.6 (D), T8.7 (D), T8.8 (D), T18.1 (B)
DEW2_OUT: D18.1 (K), J11.1 (In), T9.5 (D), T9.6 (D), T9.7 (D), T9.8 (D), T19.1 (B)
DEW_CH1: J4.32, T2.1 (B)
DEW_CH1_PWR: J4.31, R16.1, R22.1
DEW_CH2: J4.33, T3.1 (B)
DEW_CH2_PWR: J4.35, R17.1, R23.1
FAN: J4.27, T20.1 (G)
GND: BT1.2 (-), C1.2, C2.2, C3.2, C4.2, C5.2, C6.2, C7.2, C8.2, C9.1, C10.1, C11.1, C12.1, C13.2, C14.2, C15.2, C16.2, C17.1, C18.1, C19.1, C20.1, D4.2 (A), D17.2 (A), D18.2 (A), IC1.2 (GND), IC2.3 (GND), IC2.12 (GND), IC3.3 (GND), IC3.5 (~ON~/OFF), IC4.4 (V-), IC5.4 (VSS), IC6.1 (GND), J1.2, J2.4, J3.2, J4.6, J4.9, J4.14, J4.20, J4.25, J4.30, J4.34, J4.39, J5.2 (Ext), J6.2, J6.3, J7.2, J7.3, J8.2, J8.3, J9.2, J9.3, J10.2 (Ext), J11.2 (Ext), R1.2, R4.2, R5.2, R6.2, R8.2, R22.2, R23.2, R24.2, R25.2, R26.2, R27.2, T2.2 (E), T3.2 (E), T4.2 (E), T5.2 (E), T6.2 (E), T7.2 (E), T14.2 (E), T15.2 (E), T16.2 (E), T17.2 (E), T18.2 (E), T19.2 (E), T20.2 (S), T21.2 (E)
GPIO5: J4.29
GPIO17: J4.11
GPIO22: J4.15
GPIO27: J4.13
GPS_RST: J4.37, T21.1 (B)
unnamed: BT1.1 (+), C19.2, C20.2, IC2.5 (VBACKUP), R37.1
unnamed: C17.2, IC2.11 (EX_ANT), R36.1
unnamed: C18.2, J5.1 (In), R36.2
unnamed: D1.2 (A), R1.1, T1.1 (G)
unnamed: D2.1 (K), R5.1
unnamed: D3.1 (K), R6.1
unnamed: D4.1 (K), IC3.2 (OUT), L1.1
unnamed: D5.1 (K), J12.1, JP3.2 (C)
unnamed: D5.2 (A), J12.2, T20.3 (D)
unnamed: D6.1 (K), R37.2
unnamed: D11.1 (K), R28.1
unnamed: D12.1 (K), R29.1
unnamed: D13.1 (K), R30.1
unnamed: D14.1 (K), R31.1
unnamed: D15.1 (K), R32.1
unnamed: D16.1 (K), R33.1
unnamed: F1.2, R10.2, R16.2, T8.1 (S), T8.2 (S), T8.3 (S)
unnamed: F2.2, R11.2, R17.2, T9.1 (S), T9.2 (S), T9.3 (S)
unnamed: F3.1, R12.2, R18.2, T10.1 (S), T10.2 (S), T10.3 (S)
unnamed: F4.1, R13.2, R19.2, T11.1 (S), T11.2 (S), T11.3 (S)
unnamed: F5.1, R14.2, R20.2, T12.1 (S), T12.2 (S), T12.3 (S)
unnamed: F6.1, R15.2, R21.2, T13.1 (S), T13.2 (S), T13.3 (S)
unnamed: IC1.1, IC4.3 (+), R8.1
unnamed: IC2.10 (NRST), T21.3 (C)
unnamed: IC4.2 (-), IC4.6, R9.2
unnamed: J3.1, T1.2 (D)
unnamed: R10.1, T2.3 (C), T8.4 (G)
unnamed: R11.1, T3.3 (C), T9.4 (G)
unnamed: R12.1, T4.3 (C), T10.4 (G)
unnamed: R13.1, T5.3 (C), T11.4 (G)
unnamed: R14.1, T6.3 (C), T12.4 (G)
unnamed: R15.1, T7.3 (C), T13.4 (G)
unnamed: R28.2, T14.3 (C)
unnamed: R29.2, T15.3 (C)
unnamed: R30.2, T16.3 (C)
unnamed: R31.2, T17.3 (C)
unnamed: R32.2, T18.3 (C)
unnamed: R33.2, T19.3 (C)
ONE_WIRE: J4.7, JP1.1 (A), R2.1
SCL: J1.3, J4.5, JP2.2 (B), R35.1
SDA: J1.4, J4.3, JP1.3 (B), R34.1
SPI0_CE0: IC5.1 (~CS~/SHDN), J4.24
SPI0_CLK: IC5.7 (CLK), J4.23
SPI0_MISO: IC5.6 (DOUT), J4.21
SPI0_MOSI: IC5.5 (DIN), J4.19
UART_RX: IC2.2 (TX), J4.10
UART_TX: IC2.1 (RX), J4.8
VPP: F1.1, F2.1, F3.2, F4.2, F5.2, F6.2, IC1.4 (-), R7.1

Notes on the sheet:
3,0508V@20V
12V/3A
Imax: 15A
150mV@15A
Gain: 20
3,0V@15A
f=100Hz
White
Black
External BME280 Breakout board
Housing: 1455P1601
I2C addr.: 0x76 (7bit)
Min: 9V Max: 15V
3V3 Current: - Current sense, IC1: 1mA - Op-Amp, IC3: 1,5mA - DHT22, J12: 3mA - BME280, J5: 1mA - GPS modul: 25mA - GPS ext antenna: 28mA - ADC supply: 0,55mA - LEDs: 8x10mA ———————————————— apprx. 151mA
v1.0: First release
Rpi 3V3
max.800mA
2,25W@15A
PWM0
PWM1
GPIO18
GPIO23
GPIO24
GPIO25
GPIO8
GPIO7
GPIO1
GPIO16
GPIO20
GPIO4
GPIO19
GPIO6
LED light guide: MEN 12824000 https://cdn-reichelt.de/documents/datenblatt/A500/1282-1293SERIE_GER-ENG_TDS.pdf
PWR
CH1
CH2
CH3
CH4
DEW1
DEW2

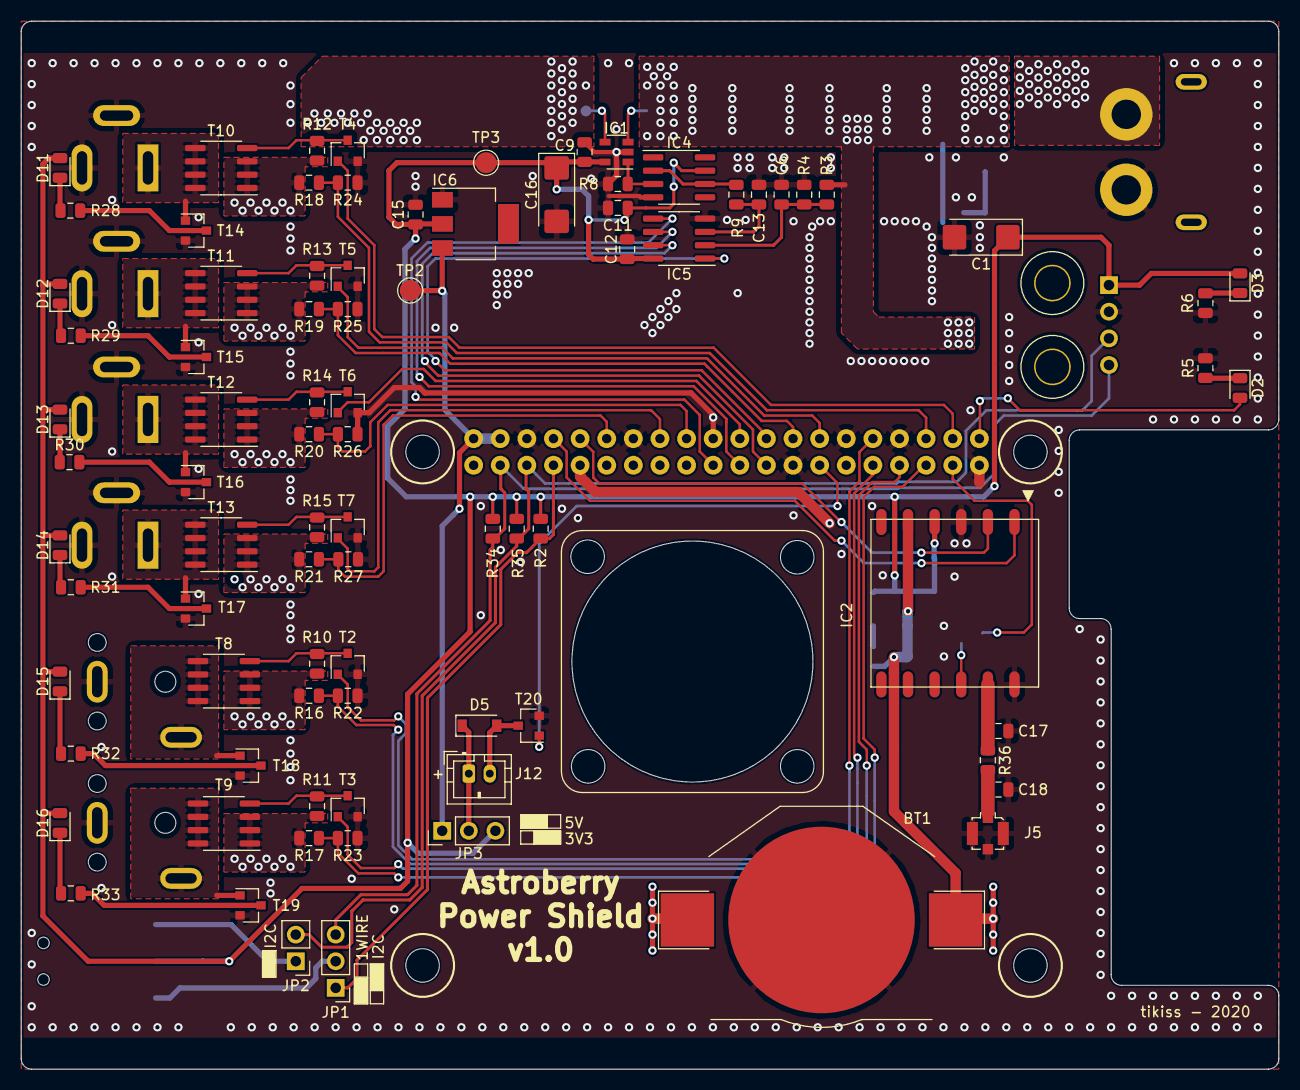
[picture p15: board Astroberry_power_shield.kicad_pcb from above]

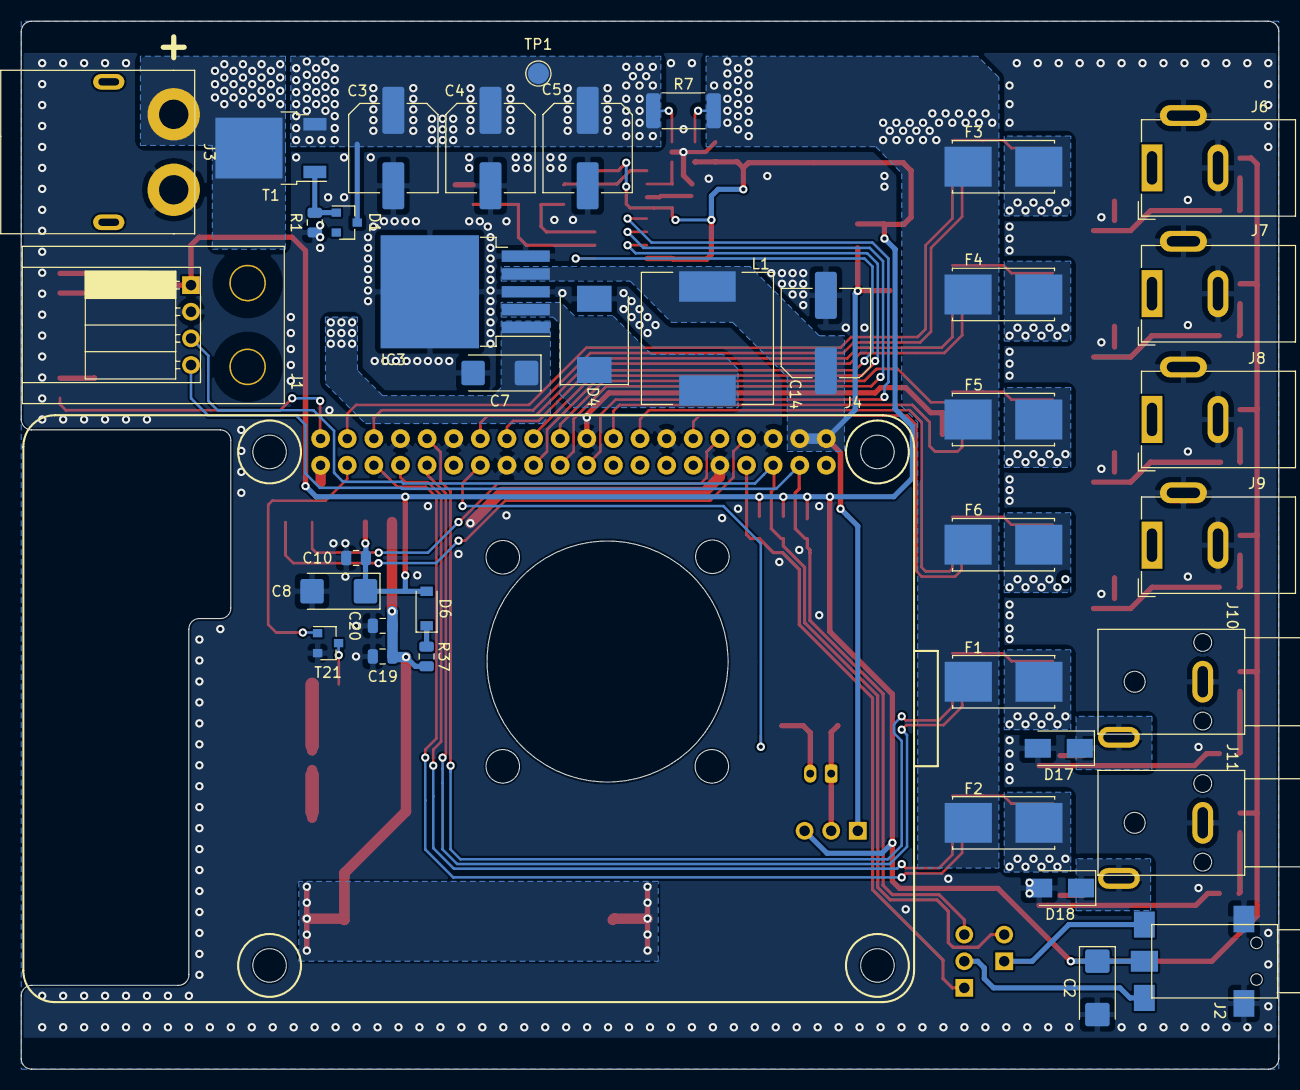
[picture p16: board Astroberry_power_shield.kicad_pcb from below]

Board: 2 copper layers, 120.0 x 100.0 mm, 128 parts (38 on the bottom side), 77 nets.

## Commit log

2020-09-25 First release
    First release upload to GitHub
    [Astroberry_Front_back-B_Cu.gbl, Astroberry_Front_back-B_Mask.gbs, Astroberry_Front_back-B_SilkS.gbo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]
2020-09-26 EBOM created
    EBOM for v1.0 is ready
    [Astroberry_power_shield_EBOM.xlsx]
2020-10-06 Update README.md
    INDI driver is on the way
